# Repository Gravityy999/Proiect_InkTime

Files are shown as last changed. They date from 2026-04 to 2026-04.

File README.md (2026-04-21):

# InkTime

## 1. Schema bloc

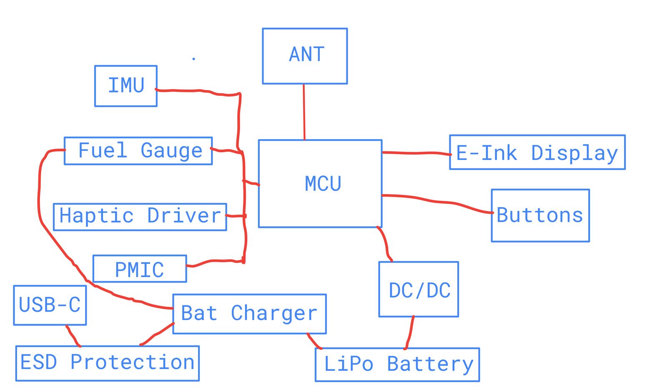
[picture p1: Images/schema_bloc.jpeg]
Schema Bloc


---

## 2. Descriere hardware

Sistemul este construit în jurul microcontrolerului **nRF52840**, fiind optimizat pentru:
- consum redus de energie
- conectivitate stabilă
- vizibilitate excelentă în lumină puternică

Pentru afișare este utilizată tehnologia **E-Paper**, care consumă energie doar la actualizarea imaginii.

---

### 2.1 Nucleul sistemului (MCU)

- **Microcontroler:** Nordic nRF52840  
- **Comunicare:** Bluetooth + periferice prin I2C și SPI  
- **Radio:**  
  - Semnalul RF este filtrat și transmis către o antenă ceramică de 2.4GHz  
  - Zona PCB de sub antenă este decupată pentru a evita atenuarea semnalului  

---

### 2.2 Managementul energiei

- **Încărcare:** BQ25180 gestionează încărcarea bateriei LiPo prin USB-C  
- **Monitorizare:** MAX17048 măsoară nivelul bateriei (I2C)  
- **Reglare tensiune:** RT6160A (Buck-Boost) menține constant 3.3V  

---

### 2.3 Afișaj și feedback

- **Ecran:** E-Paper (SPI, consum minim)  
- **Driver ecran:** Circuit cu tranzistori și diode pentru tensiunile de refresh  
- **Feedback haptic:** DRV2605 controlează motorul de vibrații  

---

### 2.4 Senzori și protecție

- **IMU (BMA423):**
  - pedometru
  - detectare ridicare mână  

- **Protecție USB:** USBLC6-2 protejează împotriva descărcărilor electrostatice  

---

### 2.5 Consum estimativ

#### Sleep Mode

I_sleep = MCU + IMU + FuelGauge + DC/DC
= 1.5 + 7 + 23 + 2 ≈ 33.5 µA

#### Active Mode

I_active ≈ 5–12 mA

#### Consum mediu

I_mediu = ((I_active × 2 min) + (I_sleep × 58 min)) / 60
≈ 365 µA

#### Autonomie

Autonomie = 100 mAh / 365 µA ≈ 274 ore

---

## 3. Pin Mapping nRF52840

| Funcție | Semnal | Pin | Descriere |
|---|---|-----|---|
| I2C SCL | I2C_SCL | P0.27 | Bus comun |
| I2C SDA | I2C_SDA | P0.26 | Bus comun |
| SPI SCK | EPD_SCK | P0.31 | Clock ecran |
| SPI MOSI | EPD_MOSI | P0.29 | Date ecran |
| EPD | EPD_BUSY | P0.05 | Status ecran |
| EPD | EPD_RST | P0.06 | Reset |
| EPD | EPD_DC | P0.08 | Data/Command |
| Buton | SW_UP | P0.11 | Navigare sus |
| Buton | SW_ENT | P0.12 | Select |
| Buton | SW_DN | P0.14 | Navigare jos |
| Haptic | EN_HAPTIC | P0.17 | Activare |
| IMU | IMU_INT1 | P0.19 | Interrupt |
| Debug | SWDIO | SWDIO | Programare |
| Debug | SWCLK | SWCLK | Clock |

---

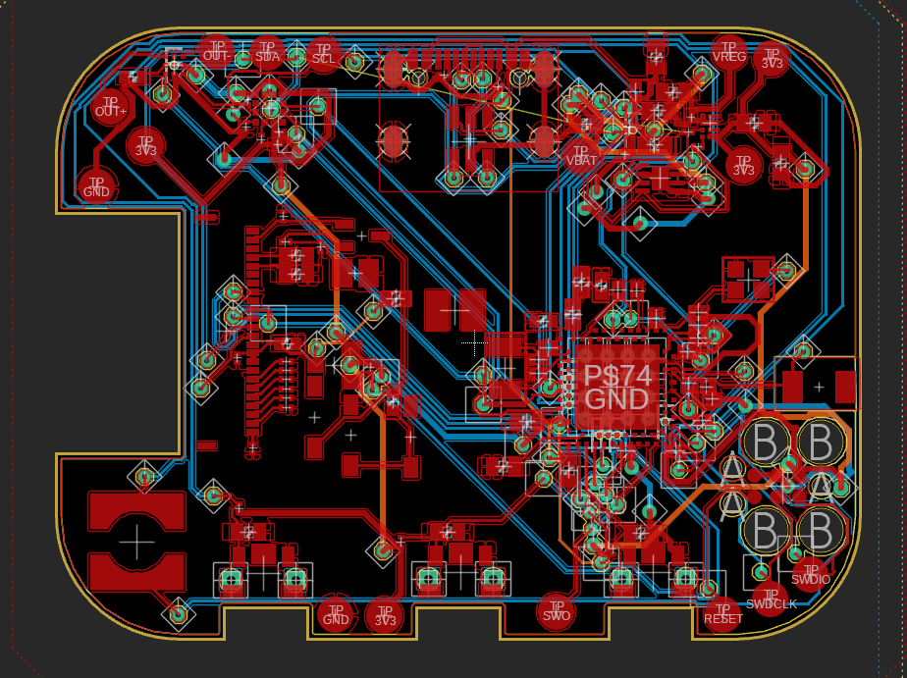
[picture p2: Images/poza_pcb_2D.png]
PCB 2D

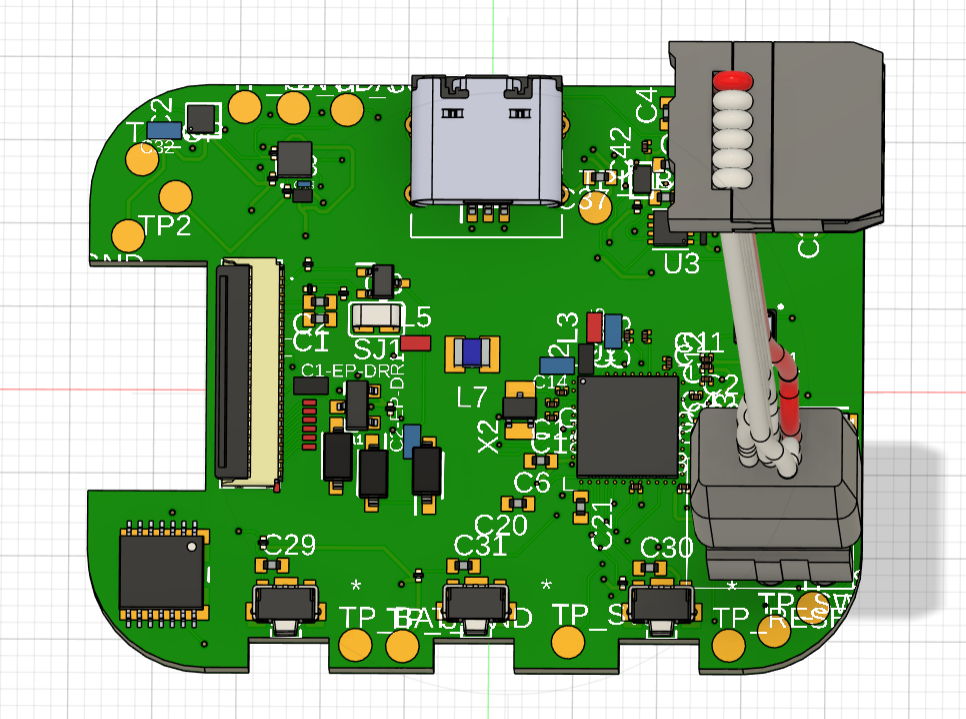
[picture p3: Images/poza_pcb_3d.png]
PCB 3D

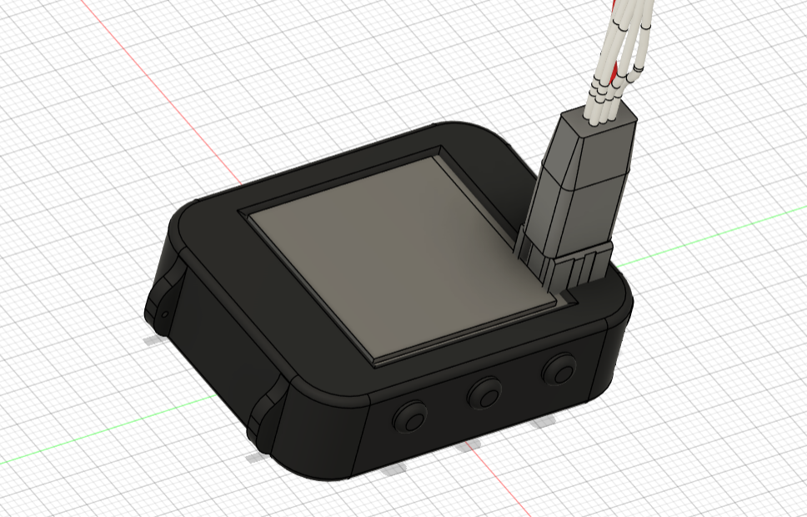
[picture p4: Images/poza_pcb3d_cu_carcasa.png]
Carcasa


---

## 4. Design

### 4.1 PCB

- Antena plasată pe margine, cu zonă fără cupru sub ea  
- PCB de **1.0 mm**, 4 layere:
  - GND
  - Power
  - Top
  - Bottom  

- Condensatori de decuplare (100nF) aproape de pini  
- Lățimi trasee:
  - Power: 0.3 mm  
  - Semnal: 0.15 mm  

#### Strategie rutare:
1. plasare componente
2. rutare semnale
3. rutare power
4. polygon pour + GND final

---

### 4.2 Carcasă și erori

- Butoanele și USB-C sunt aliniate cu carcasa  
- Erori acceptate:
  - **Dimension:** USB și butoane  
  - **ERC:** pini nefolosiți  
  - **DRC:** trasee/vias apropiate inevitabil  

---

## 5. BOM (Bill of Materials)

| Designator | Componentă | Descriere |
|---|---|---|
| U1 | nRF52840 | MCU Bluetooth |
| U2 | BQ25180 | Charger LiPo |
| U3 | MAX17048 | Fuel Gauge |
| IC1 | RT6160A | Buck-Boost |
| IC2 | BMA423 | IMU |
| IC3 | DRV2605 | Haptic Driver |
| ANT1 | 2450AT18B100E | Antenă |
| J1 | USB-C | Conector |
| J2 | FPC | E-Paper |
| C_dec | 100nF | Decuplare |
| C_bulk | 10uF | Filtrare |
| R_pu | 4.7k | Pull-up |
| L_pwr | 1uH | Inductor |
| X_32k | 32.768kHz | Cristal |
| D_esd | USBLC6-2 | Protecție ESD |

---

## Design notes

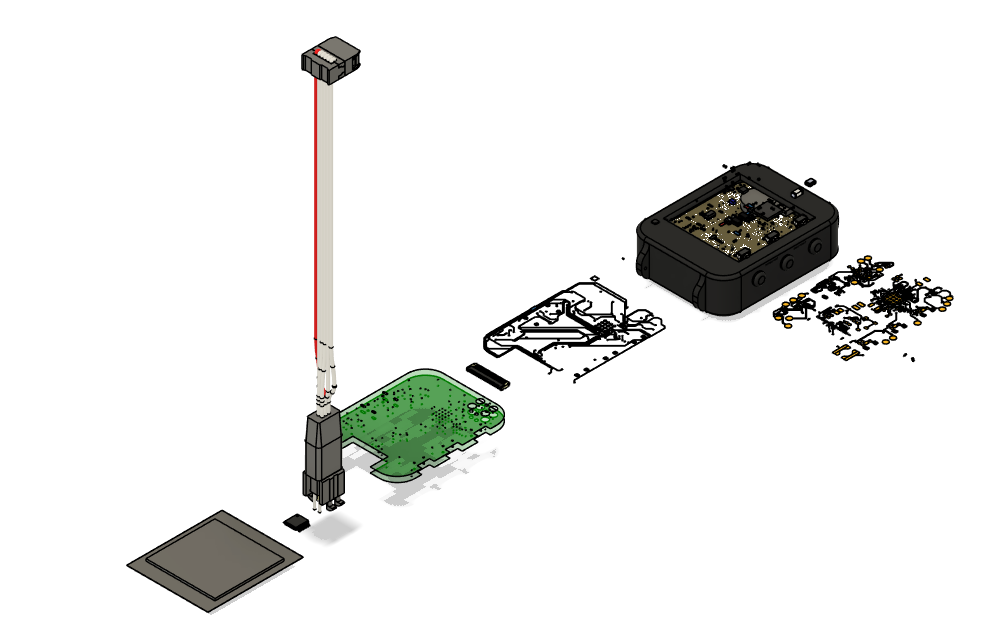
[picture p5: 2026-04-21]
Images/poza_exploaded_view.png

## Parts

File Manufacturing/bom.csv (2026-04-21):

Qty | Value | Device | Package | Parts | Description | ARROW_PART_NUMBER | ARROW_PRICE-STOCK | AVAILABILITY | CHECK_PRICES | COPYRIGHT | DESCRIPTION | DIGI-KEY_PART_NUMBER_1 | DIGI-KEY_PART_NUMBER_2 | DIGI-KEY_PART_NUMBER_3 | HEIGHT | JLCPCB | MANUFACTURER_NAME | MANUFACTURER_PART_NUMBER | MF | MFR_NAME | MOUSER_PART_NUMBER | MOUSER_PRICE-STOCK | MP | PACKAGE | POPULARITY | PRICE | PROD_ID | PURCHASE-URL | SNAPEDA_LINK | SPICEMODEL | SPICEPREFIX | TP_SIGNAL_NAME | VALUE
1 |  | ESP32_C6_LIBRARY_1_ESP32_WROVER_EAGLE-LTSPICE_CC0402 | ESP32_C6_LIBRARY_1_ESP32_WROVER_EAGLE-LTSPICE_C0402 | C37 | CAPACITOR, European symbol |  |  |  |  |  |  |  |  |  |  |  |  |  |  |  |  |  |  |  |  |  |  |  |  | NONE | C
1 |  | ESP32_C6_LIBRARY_7_JUMPER_SJ | ESP32_C6_LIBRARY_7_JUMPER_SJ | SJ1 | SMD solder JUMPER |  |  |  |  |  |  |  |  |  |  |  |  |  |  |  |  |  |  |  | 3
1 |  | NORDIC_NRF_3_CAPACITOR_0201_L | NORDIC_NRF_3_RESC0201_L | C22 | Generic chip capacitor
3 | 0 | CPF0201D7K68C1_CPF0201D7K68C1 | CPF0201D7K68C1_0201 | R2, R3, R4 | 7.68k 0201 Thin Film Surface Mount Fixed Resistor +/-0.5% 0.031W CPF0201D7K68C1
2 | 0.1uF | GRM011R60J152KE01L_1_GRM011R60J152KE01L | GRM011R60J152KE01L_1_0201 | C27, C34 | Check availability
1 | 0.1uF | GRM011R60J152KE01L_2_GRM011R60J152KE01L | GRM011R60J152KE01L_2_CAPC0201X13N | C23 | Check availability |  |  | In Stock | https://www.snapeda.com/parts/GRM011R60J152KE01L/Murata/view-part/?ref=eda |  | SMD Capacitor X5R(EIA) with Capacitance: 1500pF Tol. 10%. Rated Voltage: 6.3Vdc |  |  |  |  |  |  |  | Murata |  |  |  | GRM011R60J152KE01L | 0201 Murata |  | None |  |  | https://www.snapeda.com/parts/GRM011R60J152KE01L/Murata/view-part/?ref=snap
1 | 0.1uF | NORDIC_NRF_3_CAPACITOR_0201_L | NORDIC_NRF_3_RESC0201_L | C42 | Generic chip capacitor
8 | 0.1uF/50V | GRM011R60J152KE01L_1_GRM011R60J152KE01L | GRM011R60J152KE01L_1_0201 | EPD_C5, EPD_C6, EPD_C7, EPD_C8, EPD_C9, EPD_C10, EPD_C11, EPD_C12 | Check availability
1 | 0.47 | CPF0201D7K68C1_CPF0201D7K68C1 | CPF0201D7K68C1_0201 | R1_EP_DR1 | 7.68k 0201 Thin Film Surface Mount Fixed Resistor +/-0.5% 0.031W CPF0201D7K68C1
1 | 1.0µF | PERFECT_0402_CAP_0402 | PERFECT_0402_0402 | C15 | 0402 (1005 Metric)
1 | 100nF | GRM011R60J152KE01L_2_GRM011R60J152KE01L | GRM011R60J152KE01L_2_CAPC0201X13N | C19 | Check availability |  |  | In Stock | https://www.snapeda.com/parts/GRM011R60J152KE01L/Murata/view-part/?ref=eda |  | SMD Capacitor X5R(EIA) with Capacitance: 1500pF Tol. 10%. Rated Voltage: 6.3Vdc |  |  |  |  |  |  |  | Murata |  |  |  | GRM011R60J152KE01L | 0201 Murata |  | None |  |  | https://www.snapeda.com/parts/GRM011R60J152KE01L/Murata/view-part/?ref=snap
4 | 100nF | NORDIC_NRF_3_CAPACITOR_0201_L | NORDIC_NRF_3_RESC0201_L | C5, C7, C8, C12 | Generic chip capacitor
1 | 100pF | NORDIC_NRF_3_CAPACITOR_0201_L | NORDIC_NRF_3_RESC0201_L | C11 | Generic chip capacitor
6 | 10K | CPF0201D7K68C1_CPF0201D7K68C1 | CPF0201D7K68C1_0201 | R2_EP_DR, R5, R7, R8, R9, R_PWR_EPD | 7.68k 0201 Thin Film Surface Mount Fixed Resistor +/-0.5% 0.031W CPF0201D7K68C1
2 | 10uF | ESP32_C6_LIBRARY_1_ESP32_WROVER_EAGLE-LTSPICE_CC0402 | ESP32_C6_LIBRARY_1_ESP32_WROVER_EAGLE-LTSPICE_C0402 | C24, C39 | CAPACITOR, European symbol |  |  |  |  |  |  |  |  |  |  |  |  |  |  |  |  |  |  |  |  |  |  |  |  | NONE | C
1 | 10uF | PERFECT_0402_CAP_0402 | PERFECT_0402_0402 | C1-EP-DR | 0402 (1005 Metric)
1 | 10µH | NORDIC_NRF_2_INDUCTOR_0402_L | NORDIC_NRF_2_RESC0402_L | L2 | Generic chip inductor
4 | 12pF | NORDIC_NRF_3_CAPACITOR_0201_L | NORDIC_NRF_3_RESC0201_L | C1, C2, C17, C18 | Generic chip capacitor
1 | 15nH | NORDIC_NRF_2_INDUCTOR_0402_L | NORDIC_NRF_2_RESC0402_L | L3 | Generic chip inductor
2 | 1pF | NORDIC_NRF_3_CAPACITOR_0201_L | NORDIC_NRF_3_RESC0201_L | C3, C4 | Generic chip capacitor
4 | 1uF | ESP32_C6_LIBRARY_1_ESP32_WROVER_EAGLE-LTSPICE_CC0402 | ESP32_C6_LIBRARY_1_ESP32_WROVER_EAGLE-LTSPICE_C0402 | C29, C30, C31, C38 | CAPACITOR, European symbol |  |  |  |  |  |  |  |  |  |  |  |  |  |  |  |  |  |  |  |  |  |  |  |  | NONE | C
1 | 1uF | PERFECT_0402_CAP_0402 | PERFECT_0402_0402 | C32 | 0402 (1005 Metric)
2 | 1uF/50V | ESP32_C6_LIBRARY_1_ESP32_WROVER_EAGLE-LTSPICE_CC0402 | ESP32_C6_LIBRARY_1_ESP32_WROVER_EAGLE-LTSPICE_C0402 | EPD_C1, EPD_C2 | CAPACITOR, European symbol |  |  |  |  |  |  |  |  |  |  |  |  |  |  |  |  |  |  |  |  |  |  |  |  | NONE | C
1 | 2.2 | CPF0201D7K68C1_CPF0201D7K68C1 | CPF0201D7K68C1_0201 | R_TYPE_SEL | 7.68k 0201 Thin Film Surface Mount Fixed Resistor +/-0.5% 0.031W CPF0201D7K68C1
3 | 2025-10-22_07-23-44_LIBRARY_EVP-AKE31ASW_EVP-AKE31A_PAN | 2025-10-22_07-23-44_LIBRARY_EVP-AKE31ASW_EVP-AKE31A_PAN | 2025-10-22_07-23-44_LIBRARY_SW_EVP-AKE31A_PAN | SW_DN12, SW_ENT, SW_UP |  |  |  |  |  | Copyright (C) 2025 Ultra Librarian. All rights reserved. |  | P123437TR-ND | P123437CT-ND | P123437DKR-ND |  |  | Panasonic | EVP-AKE31A
1 | 20V/4.2A/52mO/1.4W | ESP32_C6_LIBRARY_4_ESP32_WROVER_SPARKFUN-DISCRETESEMI_MOSFET_PCH-DMG2305UX-7 | ESP32_C6_LIBRARY_4_ESP32_C6_LIBRARY_4_ESP32_C6_LIBRARY_4_ESP32_C6_LIBRARY_4_ESP32_WROVER_SPARKFUN-DISCRETESEMI_SOT23-3 | Q1 | P-channel MOSFETs |  |  |  |  |  |  |  |  |  |  |  |  |  |  |  |  |  |  |  |  |  | TRAN-14388 |  |  |  |  |  | 20V/4.2A/52mO/1.4W
2 | 22uF | ESP32_C6_LIBRARY_1_ESP32_WROVER_EAGLE-LTSPICE_CC0402 | ESP32_C6_LIBRARY_1_ESP32_WROVER_EAGLE-LTSPICE_C0402 | C25, C33 | CAPACITOR, European symbol |  |  |  |  |  |  |  |  |  |  |  |  |  |  |  |  |  |  |  |  |  |  |  |  | NONE | C
1 | 2450AT18B100E | 2450AT18B100E_2450AT18B100E | 2450AT18B100E_ANTC3216X140N | ANT1 | Antennas 2.45GHz ANTENNA | 2450AT18B100E | https://www.arrow.com/en/products/2450at18b100e/johanson-dielectrics?utm_currency=USD&region=nac |  |  |  | Antennas 2.45GHz ANTENNA |  |  |  | 1.4mm |  | JOHANSON TECHNOLOGY | 2450AT18B100E |  |  | 609-2450AT18B100E | https://www.mouser.co.uk/ProductDetail/Johanson-Technology/2450AT18B100E?qs=yCnrNFeXz%252Bh5MFsFIXGZGA%3D%3D
1 | 3.9nH | ESP32_C6_LIBRARY_2_744043680IND_4828-WE-TPC_WRE | ESP32_C6_LIBRARY_2_IND_4828-WE-TPC_WRE | L1 |  |  |  |  |  | Copyright (C) 2024 Ultra Librarian. All rights reserved. |  |  |  |  |  |  |  | 744043680 |  | Wurth Electronics
1 | 32.768kHz | NORDIC_NRF_1_XTAL_32KHZ | NORDIC_NRF_1_XTAL_3215_N | X2
1 | 32MHz | NORDIC_NRF_XTAL_32MHZ | NORDIC_NRF_BT-XTAL_2016_N | X1
2 | 3K3 | CPF0201D7K68C1_CPF0201D7K68C1 | CPF0201D7K68C1_0201 | R17, R18 | 7.68k 0201 Thin Film Surface Mount Fixed Resistor +/-0.5% 0.031W CPF0201D7K68C1
1 | 4.7uF | ESP32_C6_LIBRARY_1_ESP32_WROVER_EAGLE-LTSPICE_CC0402 | ESP32_C6_LIBRARY_1_ESP32_WROVER_EAGLE-LTSPICE_C0402 | C43 | CAPACITOR, European symbol |  |  |  |  |  |  |  |  |  |  |  |  |  |  |  |  |  |  |  |  |  |  |  |  | NONE | C
1 | 4.7uF/25V | PERFECT_0402_CAP_0402 | PERFECT_0402_0402 | C2-EP-DR1 | 0402 (1005 Metric)
3 | 4.7µF | ESP32_C6_LIBRARY_1_ESP32_WROVER_EAGLE-LTSPICE_CC0402 | ESP32_C6_LIBRARY_1_ESP32_WROVER_EAGLE-LTSPICE_C0402 | C6, C20, C21 | CAPACITOR, European symbol |  |  |  |  |  |  |  |  |  |  |  |  |  |  |  |  |  |  |  |  |  |  |  |  | NONE | C
1 | 4.7µF | PERFECT_0402_CAP_0402 | PERFECT_0402_0402 | C14 | 0402 (1005 Metric)
1 | 47nF | NORDIC_NRF_3_CAPACITOR_0201_L | NORDIC_NRF_3_RESC0201_L | C16 | Generic chip capacitor
1 | 503480-2400 | 503480-2400_503480-2400 | 503480-2400_5034802400 | J1 | FFC & FPC Connectors 0.5mm FPC RA SMT Dual Contact 24Ckt |  |  |  |  |  | FFC & FPC Connectors 0.5mm FPC RA SMT Dual Contact 24Ckt |  |  |  | 1.87mm |  | Molex | 503480-2400 |  |  | 538-503480-2400 | https://www.mouser.co.uk/ProductDetail/Molex/503480-2400?qs=OAhjpuo3Vu7efIoxFh9AOw%3D%3D
2 | 5K1 | CPF0201D7K68C1_CPF0201D7K68C1 | CPF0201D7K68C1_0201 | R1_USB, R2_USB | 7.68k 0201 Thin Film Surface Mount Fixed Resistor +/-0.5% 0.031W CPF0201D7K68C1
1 | 68uH | NORDIC_NRF_2_INDUCTOR_0402_L | NORDIC_NRF_2_RESC0402_L | L5 | Generic chip inductor
1 | 820pF | NORDIC_NRF_3_CAPACITOR_0201_L | NORDIC_NRF_3_RESC0201_L | C9 | Generic chip capacitor
1 | BMA421 | BMA423_BMA423 | BMA423_BMA423 | IC3 | Accelerometers Triaxial low-g 12bit Acceleration Sensor | BMA423 | https://www.arrow.com/en/products/bma423/bosch |  |  |  | Accelerometers Triaxial low-g 12bit Acceleration Sensor |  |  |  | 1mm |  | BOSCH | BMA423 |  |  | 262-BMA423 | https://www.mouser.co.uk/ProductDetail/Bosch-Sensortec/BMA423?qs=HXFqYaX1Q2xC%252BSgeGoX3mg%3D%3D
1 | BQ25180YBGR | BQ25180YBGR_BQ25180YBGR | BQ25180YBGR_BGA8C40P2X4_100X155X50 | IC1 | Charger IC Lithium Ion/Polymer, Lithium Iron Phosphate 8-DSBGA (1.6x1.1) | BQ25180YBGR | https://www.arrow.com/en/products/bq25180ybgr/texas-instruments?utm_currency=USD&region=nac |  |  |  | Charger IC Lithium Ion/Polymer | Lithium Iron Phosphate 8-DSBGA (1.6x1.1) |  |  |  | 0.5mm |  | Texas Instruments | BQ25180YBGR |  |  | 595-BQ25180YBGR | https://www.mouser.co.uk/ProductDetail/Texas-Instruments/BQ25180YBGR?qs=doiCPypUmgEWjAK%252BJAX6Tw%3D%3D
1 | DRV2605YZFR | DRV2605YZFR_DRV2605YZFR | DRV2605YZFR_BGA9C50P3X3_144X144X62 | IC2 | Haptic Driver for ERM/LRA with Built-In Library and Smart Loop Architecture | DRV2605YZFR | https://www.arrow.com/en/products/drv2605yzfr/texas-instruments?region=nac |  |  |  | Haptic Driver for ERM/LRA with Built-In Library and Smart Loop Architecture |  |  |  | 0.625mm |  | Texas Instruments | DRV2605YZFR
1 | FTC252012SR47MBCA | MLP2016SR47MT0S1_FTC252012SR47MBCA | MLP2016SR47MT0S1_INDC2016X100N | L7 | SMD / SMT Inductors (Coils), L=0.47?H, L x W x T : |  |  |  |  |  | SMD / SMT Inductors (Coils) | L=0.47?H | L x W x T : |  |  |  | 1mm | https://jlcpcb.com/partdetail/6763488-FTC252012SR47MBCA/C5832368 | TDK | FTC252012SR47MBCA
16 | HECTOR_WATCH_1_TPTP20R | HECTOR_WATCH_1_TPTP20R | HECTOR_WATCH_1_TP20R | TD_SDA, TP1, TP2, TP_3.3V, TP_3V3, TP_BAT_GND, TP_GND, TP_ON, TP_OP, TP_RESET, TP_SCL, TP_SWDCLK, TP_SWDIO, TP_SWO, TP_VBAT, TP_VREG | Test pad |  |  |  |  |  |  |  |  |  |  |  |  |  |  |  |  |  |  |  | 2
1 | KH-TYPE-C-16P | KH-TYPE-C-16P_KH-TYPE-C-16P | KH-TYPE-C-16P_KINGHELM_KH-TYPE-C-16P | J4 | Check availability |  |  | Not in stock | https://www.snapeda.com/parts/KH-TYPE-C-16P/Kinghelm/view-part/?ref=eda |  |  |  |  |  |  |  |  |  | kinghelm |  |  |  | KH-TYPE-C-16P | None |  | None |  |  | https://www.snapeda.com/parts/KH-TYPE-C-16P/Kinghelm/view-part/?ref=snap
1 | MAX17048G+T10 | ESP32_C6_LIBRARY_MAX17048G+T10 | ESP32_C6_LIBRARY_SON50P200X200X80-9N | U3 | Check availability |  |  | In Stock | https://www.snapeda.com/parts/MAX17048G+T10/Analog+Devices/view-part/?ref=eda |  | 3µA 1-Cell/2-Cell Fuel Gauge with ModelGauge |  |  |  |  |  |  |  | Analog Devices |  |  |  | MAX17048G+T10 | TDFN-8 Maxim |  | None |  | https://www.snapeda.com/api/url_track_click_mouser/?unipart_id=329239&manufacturer=Analog Devices&part_name=MAX17048G+T10&search_term=None | https://www.snapeda.com/parts/MAX17048G+T10/Analog+Devices/view-part/?ref=snap
3 | MBR0530 | ESP32_C6_LIBRARY_5_MBR0530 | ESP32_C6_LIBRARY_5_SOD3716X135N | D2, D4, D5 | ON SEMICONDUCTOR - MBR0530 - DIODE, SCHOTTKY, 0.5A, 30V, SOD-123 |  |  | In Stock | https://www.snapeda.com/parts/MBR0530/Onsemi/view-part/?ref=eda |  | Diode Schottky 30 V 500mA Surface Mount SOD-123 |  |  |  |  |  |  |  | ON Semiconductor |  |  |  | MBR0530 | SOD-123-2 ON Semiconductor |  | None |  | https://www.snapeda.com/api/url_track_click_mouser/?unipart_id=179458&manufacturer=ON Semiconductor&part_name=MBR0530&search_term=None | https://www.snapeda.com/parts/MBR0530/Onsemi/view-part/?ref=snap
2 | N.C | NORDIC_NRF_3_CAPACITOR_0201_L | NORDIC_NRF_3_RESC0201_L | C10, C13 | Generic chip capacitor
1 | NRF52840_QF | NORDIC_NRF_4_NRF52840_QF | NORDIC_NRF_4_AQFN50P700X700X85_HS-74N | U1 | nRF52840
1 | RT6160AWSC | RT6160AWSC_RT6160AWSC | RT6160AWSC_BGA15C40P3X5_140X230X60 | IC9 | Buck-Boost Regulator Positive Output Step-Up/Step-Down I2C DC-DC Controller IC 15-WL-CSP (BSC) (1.4x2.3) |  |  |  |  |  | Buck-Boost Regulator Positive Output Step-Up/Step-Down I2C DC-DC Controller IC 15-WL-CSP (BSC) (1.4x2.3) |  |  |  | 0.6mm |  | RICHTEK | RT6160AWSC |  |  | 835-RT6160AWSC | https://www.mouser.co.uk/ProductDetail/Richtek/RT6160AWSC?qs=amGC7iS6iy%2FLd9PSoixZXQ%3D%3D
1 | SI1308EDL-T1-GE3 | ESP32_C6_LIBRARY_6_SI1308EDL-T1-GE3 | ESP32_C6_LIBRARY_6_SOT65P210X110-3N | Q3 | MOSFET N-Ch 30V 1.5A TrenchFET SC70 Vishay Si1308EDL-T1-GE3 N-channel MOSFET Transistor, 1.5 A, 30 V, 3-Pin SC-70 |  |  | In Stock | https://www.snapeda.com/parts/SI1308EDL-T1-GE3/Vishay+Siliconix/view-part/?ref=eda |  | Si1308EDL-T1-GE3 N-channel MOSFET Transistor | 1.5 A | 30 V | 3-Pin SC-70 | Siliconix / Vishay SI1308EDL-T1-GE3 |  |  |  |  |  |  |  | Vishay Siliconix |  |  |  | SI1308EDL-T1-GE3 | SOT-323 Vishay Semiconductor |  | None |  | https://www.snapeda.com/api/url_track_click_mouser/?unipart_id=274603&manufacturer=Vishay Siliconix&part_name=SI1308EDL-T1-GE3&search_term=None | https://www.snapeda.com/parts/SI1308EDL-T1-GE3/Vishay+Siliconix/view-part/?ref=snap
1 | TC2030-IDC_TC2030-IDC | TC2030-IDC_TC2030-IDC | TC2030-IDC_TC2030IDC | J2 | CABLE ADAPTER 6 POS |  |  |  |  |  | CABLE ADAPTER 6 POS |  |  |  | 19mm |  | Tag Connect | TC2030-IDC
1 | USBLC6-2SC6Y | ESP32_C6_LIBRARY_3_USBLC6-2SC6Y | ESP32_C6_LIBRARY_3_SOT95P280X145-6N | D3 | Low Cap. ESD Protection Auto SOT-23-6 STMicroelectronics USBLC6-2SC6Y, Dual Uni-Directional TVS Diode Array, 6-Pin SOT-23 |  |  | In Stock | https://www.snapeda.com/parts/USBLC6-2SC6Y/STMicroelectronics/view-part/?ref=eda |  | 17V Clamp 5A (8/20µs) Ipp Tvs Diode Surface Mount SOT-23-6 |  |  |  |  |  |  |  | STMicroelectronics |  |  |  | USBLC6-2SC6Y | SOT-23-6 STMicroelectronics |  | None |  |  | https://www.snapeda.com/parts/USBLC6-2SC6Y/STMicroelectronics/view-part/?ref=snap

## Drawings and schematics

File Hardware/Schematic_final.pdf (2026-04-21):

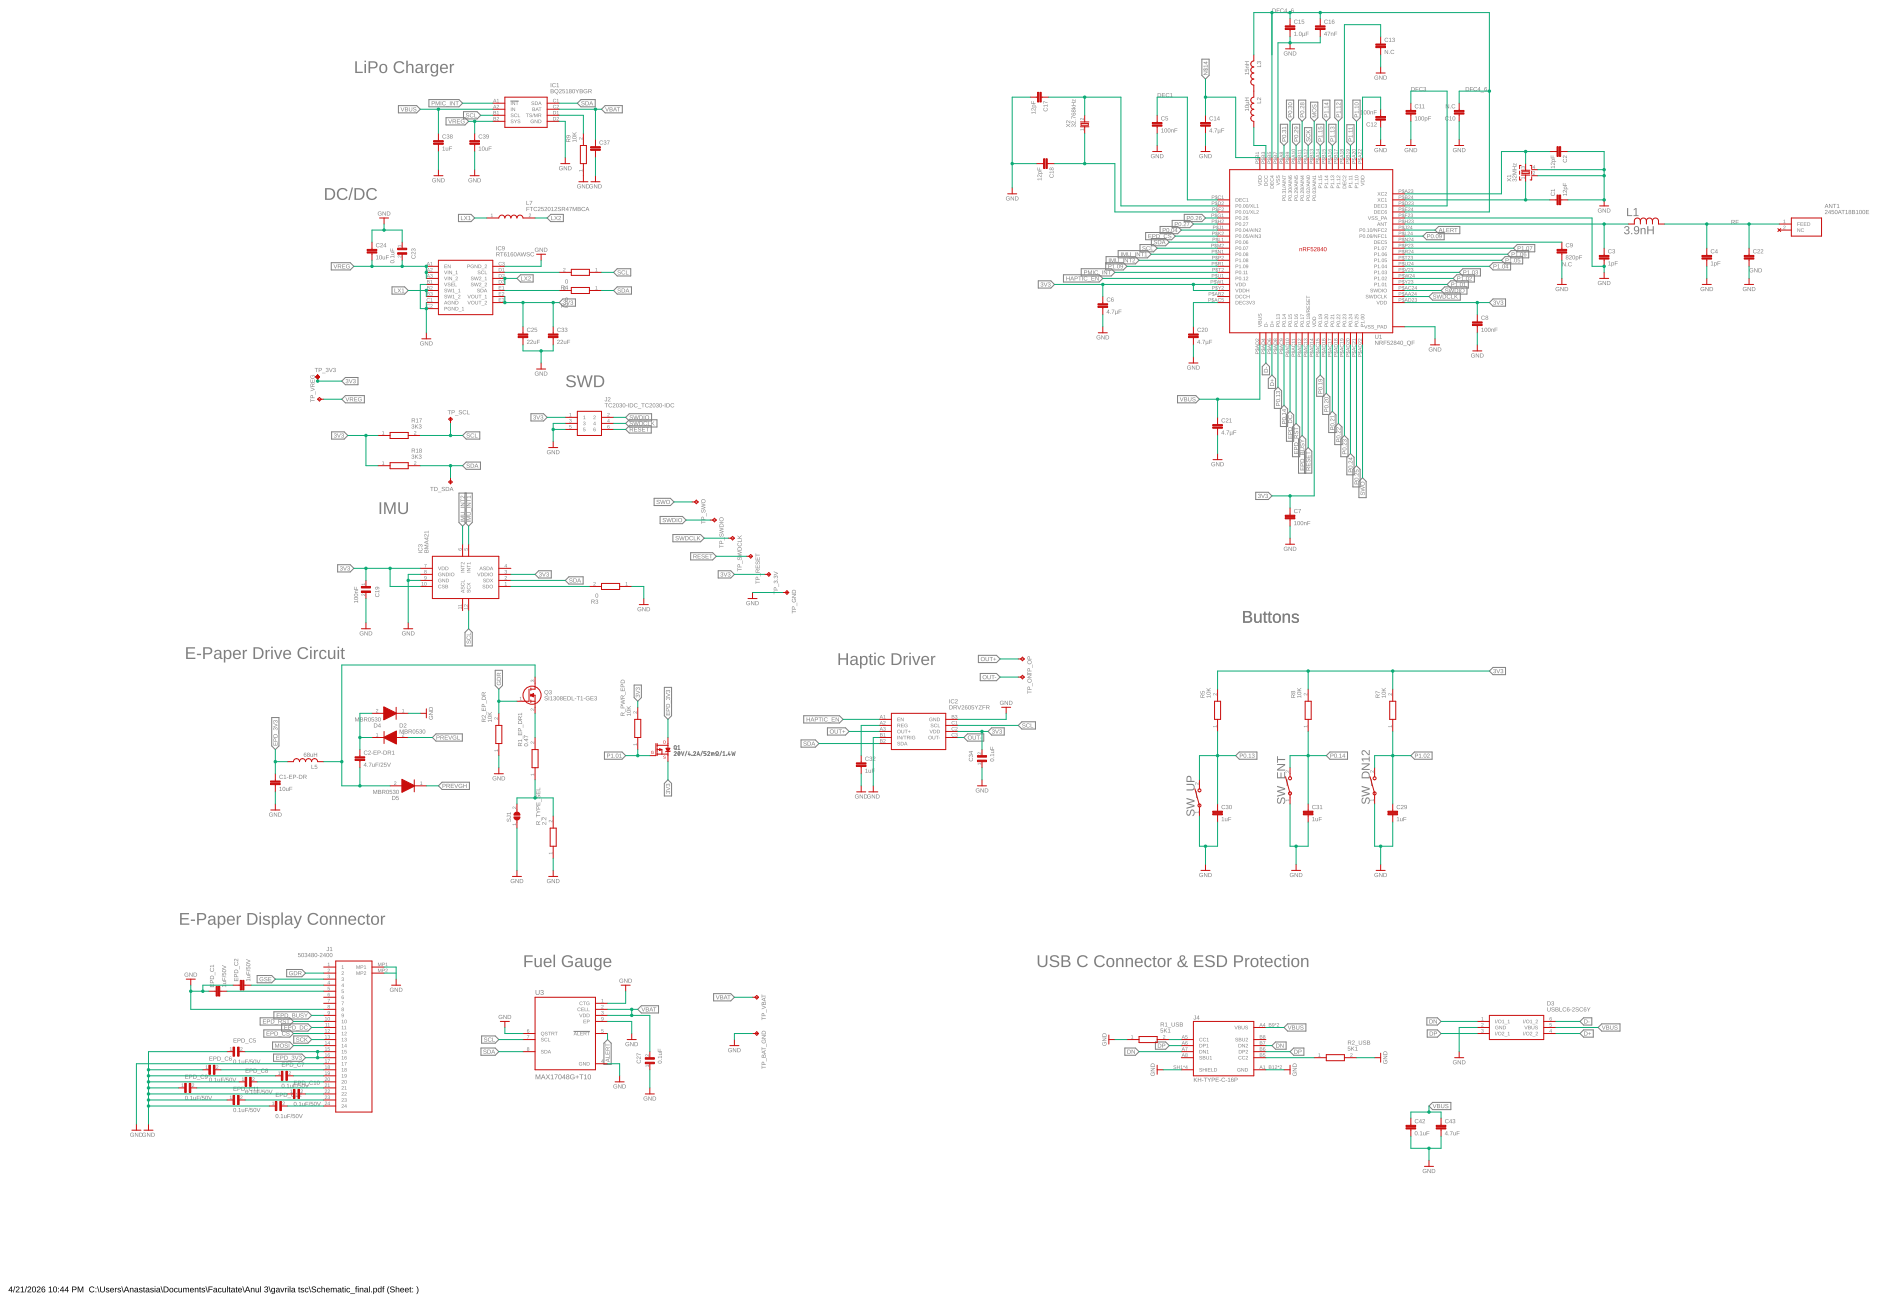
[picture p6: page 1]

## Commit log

2026-04-20 Revise README with project details and specifications
    Updated project name and added detailed hardware description, including system architecture, energy management, display feedback, sensor information, estimated consumption, pin mapping, PCB design, a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
2026-04-21 Update PCB 3D image reference in README
2026-04-21 Fix image filename case for PCB 3D
